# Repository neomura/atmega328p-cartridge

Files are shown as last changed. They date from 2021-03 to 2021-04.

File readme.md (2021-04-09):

# neomura/atmega328p-cartridge

Circuit design and games engine for ATMega328P-based cartridges for the Neomura retro games console.

Derived from the [Arduinocade project](https://github.com/rossumur/Arduinocade).

| Link | Description |
| --- | --- |
| [License](./license.md) | MIT License. |
| [Documentation](./documentation/readme.md) | Documentation regarding this project. |
| [Circuit Design](./circuit-design/readme.md) | KiCad files and assembly instructions for the PCB. |
| [Engine](./engine/readme.md) | Source code for the games engine. |
| [Palette](./palette.aseprite) | Aseprite palette; each group of four colors is an available palette for a scanline. |

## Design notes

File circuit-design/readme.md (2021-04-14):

# [neomura/atmega328p-cartridge](../readme.md)/Circuit Design

| Link | Description |
| --- | --- |
| [cartridge.pro](./cartridge.pro) | KiCAD project. |
| [cartridge.sch](./cartridge.sch) | KiCAD schematic. |
| [cartridge.kicad_pcb](./cartridge.kicad_pcb) | KiCAD PCB layout. |

## Bill of materials

Links are included for reference only and are not endorsements.

| Reference | Description | Model No. | Link |
| --- | --- | --- | --- |
| J1 | Cartridge connector (right-angled 1x15 2.54mm male pin header) | Unknown | [https://www.aliexpress.com/item/4000660389713.html?spm=a2g0s.9042311.0.0.65b74c4dMpBmdG](https://www.aliexpress.com/item/4000660389713.html?spm=a2g0s.9042311.0.0.65b74c4dMpBmdG) |
| J2 | ICSP header (right-angled 1.5 2.54mm male pin header) | Unknown | [https://www.bitsbox.co.uk/index.php?main_page=product_info&cPath=225_230&products_id=3128](https://www.bitsbox.co.uk/index.php?main_page=product_info&cPath=225_230&products_id=3128) |
| U1 | Microcontroller | ATMega328P-PU | [https://www.bitsbox.co.uk/index.php?main_page=product_info&cPath=140_161_162&products_id=1225](https://www.bitsbox.co.uk/index.php?main_page=product_info&cPath=140_161_162&products_id=1225) |
| X1 | 14.31818MHz (NTSC) or 17.734MHz (PAL 60) HC-49S crystal | Unknown | [https://www.aliexpress.com/item/32496964768.html?spm=a2g0s.9042311.0.0.65b74c4dMpBmdG](https://www.aliexpress.com/item/32496964768.html?spm=a2g0s.9042311.0.0.65b74c4dMpBmdG) or [https://www.ebay.co.uk/itm/20pcs-17-734MHz-HC-49S-Crystal-Oscillator-Passive-Quartz-Resonator/253056403948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](https://www.ebay.co.uk/itm/20pcs-17-734MHz-HC-49S-Crystal-Oscillator-Passive-Quartz-Resonator/253056403948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) |
| R1 | 1M load resistor | Unknown | [https://www.bitsbox.co.uk/index.php?main_page=product_info&cPath=83_84_85&products_id=480](https://www.bitsbox.co.uk/index.php?main_page=product_info&cPath=83_84_85&products_id=480) |
| C1/C2 | 22pF load capacitor | Unknown | [https://www.bitsbox.co.uk/index.php?main_page=product_info&cPath=65_75_67&products_id=187](https://www.bitsbox.co.uk/index.php?main_page=product_info&cPath=65_75_67&products_id=187) |
| D1 | Reset protection diode | 1N4148 | [https://www.bitsbox.co.uk/index.php?main_page=product_info&cPath=140_141_143&products_id=925](https://www.bitsbox.co.uk/index.php?main_page=product_info&cPath=140_141_143&products_id=925) |
| R2 | 4.7k reset pull-up resistor | Unknown | [https://www.bitsbox.co.uk/index.php?main_page=product_info&cPath=83_84_85&products_id=452](https://www.bitsbox.co.uk/index.php?main_page=product_info&cPath=83_84_85&products_id=452) |
| C3 | 100nF reset bypass capacitor | Unknown | [https://www.bitsbox.co.uk/index.php?main_page=product_info&cPath=65_75_67&products_id=210](https://www.bitsbox.co.uk/index.php?main_page=product_info&cPath=65_75_67&products_id=210) |
| C4 | 100nF +5V bypass capacitor | Unknown | [https://www.bitsbox.co.uk/index.php?main_page=product_info&cPath=65_75_67&products_id=210](https://www.bitsbox.co.uk/index.php?main_page=product_info&cPath=65_75_67&products_id=210) |
| R3 | 470R video carrier resistor | Unknown | [https://www.bitsbox.co.uk/index.php?main_page=product_info&cPath=83_84_85&products_id=441](https://www.bitsbox.co.uk/index.php?main_page=product_info&cPath=83_84_85&products_id=441) |
| R4 | 1K video sync resistor | Unknown | [https://www.bitsbox.co.uk/index.php?main_page=product_info&cPath=83_84_85&products_id=445](https://www.bitsbox.co.uk/index.php?main_page=product_info&cPath=83_84_85&products_id=445) |
| R5/R7 | 270R audio low-pass resistor | Unknown | [https://www.bitsbox.co.uk/index.php?main_page=product_info&cPath=83_84_85&products_id=438](https://www.bitsbox.co.uk/index.php?main_page=product_info&cPath=83_84_85&products_id=438) |
| C5/C7 | 33nF audio low-pass capacitor | Unknown | [https://www.bitsbox.co.uk/index.php?main_page=product_info&cPath=65_75_67&products_id=208](https://www.bitsbox.co.uk/index.php?main_page=product_info&cPath=65_75_67&products_id=208) |
| R6/R8 | 150R audio output resistor | Unknown | [https://www.bitsbox.co.uk/index.php?main_page=product_info&cPath=83_84_85&products_id=435](https://www.bitsbox.co.uk/index.php?main_page=product_info&cPath=83_84_85&products_id=435) |
| C6/C8 | 10uF audio output capacitor | Unknown | [https://www.amazon.co.uk/gp/product/B08D647KCD/ref=ppx_yo_dt_b_asin_title_o00_s00?ie=UTF8&psc=1](https://www.amazon.co.uk/gp/product/B08D647KCD/ref=ppx_yo_dt_b_asin_title_o00_s00?ie=UTF8&psc=1) |

### Possible substitutions

#### J1

Right-angled male pin headers appear to come in two distinct styles; one where the plastic retainer is in contact with the PCB, and one where it is instead in contact with the corresponding female socket.  This PCB is designed for the latter, and the former will not fit inside a cartridge shell.

#### J2

In contrast to J1, this must be the style with the plastic retainer in contact with the PCB to fit inside a cartridge shell.  This can be substituted for a vertical pin header (or a socket) if it does not need to fit inside a cartridge shell.

#### U1

Other pin-compatible ATMega ICs may work.  Note that most will have smaller flash space and may not be able to store complex games.

#### X1/R1/C1/C2

Most 14.31818MHz crystals which are HC49 or smaller will work as long as appropriate bypass capacitors and resistor are included.  To be compatible with Arduinocade games instead of Neomura games, a 28.6363MHz crystal such as [https://www.aliexpress.com/item/32910067235.html?spm=a2g0s.9042311.0.0.5bfd4c4d3a2EOO](https://www.aliexpress.com/item/32910067235.html?spm=a2g0s.9042311.0.0.5bfd4c4d3a2EOO) may be used instead.

It may be possible to omit the load resistor.

#### D1

This diode is included to prevent accidental high-voltage programming.  It can be omitted.

## Assembly instructions

- Start by soldering J1 and J2.  I would recommend using some kind of clamp such as a crocodile clip to keep it firmly attached to the board (note that it will act as a heatsink, making soldering more difficult, if in contact with pins).  Use short bursts of high heat and allow time to cool between joints to avoid melting the plastic retainer.  After soldering, use a female socket to ensure that pins are straight, and use said female socket to correct the pins if not parallel with the PCB.
- Solder all other components.  There is not much room inside the shell once constructed, so ensure that these are as close to the board top as possible and that leads are clipped short.
- Place the PCB, logo up, into the back half of the shell.
- Place the front half of the shell on top and press fit.  Be careful to ensure that no components will be crushed, such as C1 and C2; you may need to stand these at 45 degrees to avoid contact with the front half of the case.

### Program

J2 is all pins except VCC of a standard 2x3 ICSP header.  These have been arranged to match pins 10-13 of an Arduino used as a programmer.

If using an [Arduino as an ISP](https://www.arduino.cc/en/Tutorial/BuiltInExamples/ArduinoISP), connect the following pins (where the Arduino has multiple pins labelled the same, any will work):

| Arduino | ICSP  |
| --- | ----- |
| GND | GND.  |
| 5V | VCC.  |
| 13 | SCK.  |
| 12 | MISO. |
| 11 | MOSI. |
| 10 | RST.  |

#### Set fuse bits

By default, an ATMega328P will use its internal 8MHz clock rather than an external crystal.  To configure this, use [AVRDUDE](https://www.nongnu.org/avrdude/) to set the correct fuse bits:

```shell
avrdude -pM328P -Ulfuse:w:0xf7:m -Uhfuse:w:0xde:m -Uefuse:w:0xfd:m
```

Note that you will need to add command line arguments to this to specify which programmer you are using, for example:

| Programmer | Suffix |
| --- | --- |
| USBtiny | -cusbtiny |
| Arduino as ISP on COM port 3 under Windows | -cavrisp -b 19200 -Pcom3 |
| Arduino as ISP on COM port 3 under Linux | -cavrisp -b 19200 -P/dev/ttyS3 |

If you are running AVRDUDE under Windows Subsystem for Linux, you may find that the remapped COM ports do not work.  In these instances, running AVRDUDE under Windows at least once seems to resolve this.

You may see an error that the extended fuse could not be written.  This is normal, as not all of its bits are writable; it could be argued to be more of an AVRDUDE bug that it tried to check them.

#### Flash

Next, write a program to flash.  Make sure that a .hex file to write exists in the current working directory, then execute:

```shell
avrdude -pM328P -Uflash:w:name-of-your-hex-file.hex
```

As before, you will need to add command line arguments to specify the correct programmer.

After following these steps, you should be able to connect the video pin (cartridge left 1) to the composite video input on a NTSC-compatible display and see a picture.

## References

| Link | Description |
| --- | --- |
| [https://www.instructables.com/Adding-ICSP-header-to-your-ArduinoAVR-board/](https://www.instructables.com/Adding-ICSP-header-to-your-ArduinoAVR-board/) | Source for ICSP header layout. |
| [https://www.arduino.cc/en/Tutorial/BuiltInExamples/ArduinoISP](https://www.arduino.cc/en/Tutorial/BuiltInExamples/ArduinoISP) | Details on using an Arduino as an ISP. |
| [https://forum.arduino.cc/index.php?topic=71580.0](https://forum.arduino.cc/index.php?topic=71580.0) | Source for default Arduino fuses. |
| [https://www.avrfreaks.net/forum/unable-reset-fuses-atmega328p](https://www.avrfreaks.net/forum/unable-reset-fuses-atmega328p) | Workaround for AVRDUDE problem. |
| [https://www.ladyada.net/learn/avr/avrdude.html](https://www.ladyada.net/learn/avr/avrdude.html) | AVRDUDE instructions. |

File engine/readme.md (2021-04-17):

# [neomura/atmega328p-cartridge](../readme.md)/Engine

This engine is written in [AVRA assembler](https://github.com/Ro5bert/avra).

## Flow

The reset vector starts by running through setup routines for the engine and game.

It then enters the main loop, with the the engine's interrupt interacting with hardware and advancing global state which the main loop tracks to raise events.

## Registers

The ATMega328P has enough general-purpose registers that with the limited cycles available frequently used information is best kept in a register rather than repeatedly storing to (costing 2 cycles) and loading from (costing 2 cycles) SRAM.  Additionally, if registers used by the main loop and interrupts overlap as little as possible, the push (2 cycles) and pop (2 cycles) normally required to prevent corruption of main loop state from interrupts can be avoided as well.  In practice, few game logic or driver operations require more than 4 general purpose registers.

Some registers have special purposes:

- `r0` and `r1` receive the result of the instructions `fmul`, `fmuls`, `fmulsu`, `mul`, `muls` and `mulsu`.
- `r26`/`r27`, `r28`/`r29` and `r30`/`r31` are labelled `X`, `Y` and `Z` respectively and are used for indirect load, store and jump.

If these are used, they are considered to belong to the main loop, and any interrupts must back them up (using `push`) beforehand and restore them (using `pop`) before `reti` (alongside `SREG`).

`r0` through `r15` are not directly usable with the instructions `cpi`, `fmul`, `fmuls`, `fmulsu`, `muls`, `mulsu`, `cbr`, `ldi`, `lds`, `ori`, `sbci`, `sbr`, `ser`, `sts`, `subi`, `andi` or `cbr`.  Consequently, if a use is found which is not made impossible or awkward through this limitation, these registers should be prioritized to leave the more flexible r16-r31 available for other operations.

The resulting mapping is as follows:

| Register | Name | Description |
| --- | --- | --- |
| `r0` | N/A | Output for some instructions. |
| `r1` | N/A | Output for some instructions. |
| `r2` | `pad_0` | State of pad 0 (set bits indicate held buttons, ordered face right, face left, select, start, up, down, left, right; all cleared when pad disconnected). |
| `r3` | `pad_1` | State of pad 1 (set bits indicate held buttons, ordered face right, face left, select, start, up, down, left, right; all cleared when pad disconnected). |
| `r4` | `pad_2` | State of pad 2 (set bits indicate held buttons, ordered face right, face left, select, start, up, down, left, right; all cleared when pad disconnected). |
| `r5` | `pad_3` | State of pad 3 (set bits indicate held buttons, ordered face right, face left, select, start, up, down, left, right; all cleared when pad disconnected). |
| `r6` | `main_loop_previous_video_row` | Used by the main loop for state tracking. |
| `r7` | `zero` | Always contains zero. |
| `r8` | `game_general_purpose_low_a` | Available for general purpose usage, though note that many instructions cannot be used with it directly. |
| `r9` | `game_general_purpose_low_b` | Available for general purpose usage, though note that many instructions cannot be used with it directly. |
| `r10` | `game_general_purpose_low_c` | Available for general purpose usage, though note that many instructions cannot be used with it directly. |
| `r11` | `game_general_purpose_low_d` | Available for general purpose usage, though note that many instructions cannot be used with it directly. |
| `r12` | `game_general_purpose_low_e` | Available for general purpose usage, though note that many instructions cannot be used with it directly. |
| `r13` | `game_general_purpose_low_f` | Available for general purpose usage, though note that many instructions cannot be used with it directly. |
| `r14` | `game_general_purpose_low_g` | Available for general purpose usage, though note that many instructions cannot be used with it directly. |
| `r15` | `game_general_purpose_low_h` | Available for general purpose usage, though note that many instructions cannot be used with it directly. |
| `r16` | `video_next_row` | The row which the interrupt will be outputting next.  Will remain 0 for longer than other values, in which `game_tick` is executed by the main loop. |
| `r17` | `interrupt_state` | Used by the interrupt to track progress through the current frame. |
| `r18` | `interrupt_flags` | Flags used internally by by the interrupt. |
| `r19` | `game_general_purpose_high_a`  | Available for general purpose usage. |
| `r20` | `game_general_purpose_high_b`  | Available for general purpose usage. |
| `r21` | `game_general_purpose_high_c`  | Available for general purpose usage. |
| `r22` | `game_general_purpose_high_d`  | Available for general purpose usage. |
| `r23` | `game_general_purpose_high_e`  | Available for general purpose usage. |
| `r24` | `game_general_purpose_high_f`  | Available for general purpose usage. |
| `r25` | `game_general_purpose_high_g`  | Available for general purpose usage. |
| `r26` | N/A | `X` (low). |
| `r27` | N/A | `X` (high). |
| `r28` | N/A | `Y` (low). |
| `r29` | N/A | `Y` (high). |
| `r30` | N/A | `Z` (low). |
| `r31` | N/A | `Z` (high). |

## Creating a game

Use AVRA to compile the engine's [main file](./engine/main.asm).

This directory and your game's source directory must be added as include paths.

Define exactly one of the following to select a video standard:

- `NTSC`
- `PAL_60`

An example command line is as follows, assuming that the current working directory is the game's source directory:

`avra -o game.hex submodules/neomura/atmega328p-cartridge/engine/engine/main.asm --includedir submodules/neomura/atmega328p-cartridge/engine --define NTSC`

This expects a number of files to exist:

### [`game/declarations/index.asm`](../example/game/declarations/index.asm)

Use this file to declare any constants, SRAM or register mappings which will be used in other files.  You will need to include the globals of any [drivers](./engine/drivers/readme.md) you use.

### [`game/implementation/setup.asm`](../example/game/implementation/setup.asm)

Use this file to configure any SRAM or registers prior to the game starting.  `r31` should be safe to use here.

### [`game/implementation/frame.asm`](../example/game/implementation/frame.asm)

This file is executed once per frame, by the main loop.  It is executed before the first execution of `game/row.asm` during a frame.  This is the only time that pad state registers should be read from.

### [`game/implementation/row.asm`](../example/game/implementation/row.asm)

This file is executed once per pixel row, by the main loop.  It should be used to communicate prepare the next line's framebuffer.

### [`game/implementation/sample.asm`](../example/game/implementation/sample.asm)

This file is executed by the interrupt once per audio sample, at approximately 15750Hz.  `r28`, `r29`, `r30` and `r31` can be freely clobbered; any other registers must be `push`ed before use and `pop`ped before exit if they are used anywhere else in the program.

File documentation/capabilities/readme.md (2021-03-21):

# [neomura/atmega328p-cartridge](../../readme.md)/[Documentation](../readme.md)/Capabilities

## Video

| Specification  | Value |
| --- | --- |
| Video standard | NTSC or PAL 60. |
| Resolution | 156x113. |
| Refresh rate | 60Hz. |
| Colors | 6, selecting 1 of 2 palettes of 4 colors per line. |

### Palette

Palette.

Colors as captured from a prototype unit running into a CSL USB 2.0 Audio/Video Grabber and will likely differ.

## Audio

| Specification | Value |
| --- | --- |
| Channels | 2 |
| Bit depth | 8 |
| Sample Rate | 15,699.72587719298Hz |

## Pads

Up to 4 pads are simultaneously supported.

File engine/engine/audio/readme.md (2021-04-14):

# [neomura/atmega328p-cartridge](../../../readme.md)/[Engine](../../readme.md)/Audio
TODO
These helper functions generate various waveforms which can be mixed to produce game audio.

| Link | Description |
| --- | --- |
| [Noise (mono)](./noise_mono/readme.md) | Monaural 15-bit linear-feedback shift register noise generator. |
| [Pulse (mono)](./pulse_mono/readme.md) | Monaural pulse wave generator with variable duty cycle. |
| [Sawtooth (mono)](./sawtooth_mono/readme.md) | Monaural rising sawtooth wave generator. |
| [Triangle (mono)](./triangle_mono/readme.md) | Monaural triangle wave generator. |

## Pattern

Most will follow a pattern like the following, assuming that the oscillator is called "example":

```assembly
; This is a block of bytes which will control the oscillator and allow it to track its state between samples.
example_register: .byte AUDIO_EXAMPLE_REGISTER_BYTES

.macro game_setup
  audio_example_setup example_register, r16
.endm

.macro game_frame
  ; Oscillators will include helpers to read/write specific areas of their registers.
  ; Frequency control uses a "rate", which is the amount by which their internal counters increment every sample.
  lds r16, example_register + AUDIO_EXAMPLE_REGISTER_RATE

  ; Increase this rate once per frame.
  inc r16

  lds example_register + AUDIO_EXAMPLE_REGISTER_RATE, r16
.endm

.macro game_sample
  ; Most oscillators use r0 and r1.
  push r0
  push r1

  ; Generate the next audio sample.  Most oscillators output to r1.
  audio_example_sample example_register

  out OCR0B, r1
  out OCR0A, r1

  pop r1
  pop r0
.endm
```

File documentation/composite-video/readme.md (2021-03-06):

# [neomura/atmega328p-cartridge](../../readme.md)/[Documentation](../readme.md)/Composite Video

Composite video is that which flows over the yellow cable of the yellow-white-and-red RCA cables often seen on games consoles between 1990 and 2010.

While it is a video protocol, the way in which it works is tightly bound to how a classic CRT (boxy) TV works, which must also be understood to appreciate why composite video is specified how it is.

CRT TV.

A CRT TV has a glass screen which displays a picture.  Behind it is an electron gun.  When energized, this fires a laser-like beam of electrons at the back of the glass, which illuminates a spot of the phosphor on the rear side of the glass.  The electron gun's output can be be controlled electronically to change the brightness of this spot.  Electromagentic coils can then deflect this beam of electrons between the gun and the glass, which allows the spot to be moved around the screen electronically.

Early arcade games directly interfaced the game with these electromagnetic coils, such as Atari's Battlezone, Star Wars and Tempest, allowing for crisp line drawings to be shown.  Composite video does not grant this level of control; instead, the beam scans from the top of the screen to the bottom, zig-zagging from left to right and back on the way down.

Zig-zag pattern.

To start a frame (pull the gun to the top of the screen), a VSYNC (vertical synchronization) signal is sent.  This is a pulse wave alternating between 0 and -40 IRE (1 IRE = 1/140V).

Example odd vertical sync signal.

| Statistic | | | | | | | | | | | | | | | | | | | | | | | | | | | | | | | | |
| --- | --- | -- | --- | -- | --- | -- | --- | -- | --- | -- | --- | -- | --- | - | --- | - | --- | - | --- | - | --- | - | --- | -- | --- | -- | --- | -- | --- | -- | --- | -- |
| Duration (µs) | 2 | 30 | 2 | 30 | 2 | 30 | 2 | 30 | 2 | 30 | 2 | 30 | 30  | 2 | 30  | 2 | 30  | 2 | 30  | 2 | 30  | 2 | 2 | 30 | 2 | 30 | 2 | 30 | 2 | 30 | 2 | 30 |
| Level (IRE) | -40 | 0  | -40 | 0  | -40 | 0  | -40 | 0  | -40 | 0  | -40 | 0  | -40 | 0 | -40 | 0 | -40 | 0 | -40 | 0 | -40 | 0 | -40 | 0  | -40 | 0  | -40 | 0  | -40 | 0  | -40 | 0  |

The middle section which spends more time at -40IRE than 0IRE is the VSYNC signal itself; the preceding and following signals are known as equalization pulses and exist to assist the electronics in older TVs.

After this signal, a repeating pattern is sent:

Example signal for a scanline.

First is a 4.7µs -40IRE HSYNC (horizontal synchronization) pulse.  This instructs the TV to return the gun to the left of the screen.  There is a short "porch" in which 0IRE is sent, and then, the active video region.

The active region is an analog segment in which voltages between 7.5IRE and 100IRE map to the full luminance range available; 7.5IRE represents black, and 100IRE represents white.  Given the above signal, you could expect to see:

Above example, rasterized.

After the active region, there is another, shorter porch of 0IRE.

These timings break down as:

| Duration (µs) | Description |
| --- | --- |
| 4.7 | HSYNC pulse.  |
| 4.7 | Porch. |
| 52.6 | Active video. |
| 1.5 | Porch. |

Totalling 63.5µs.

This will repeat until the next VSYNC signal.  This VSYNC signal, however, will be somewhat different:

Example even vertical sync signal.

| Statistic | | | | | | | | | | | | | | | | | | | | | | | | | | | | |
| --- | --- | -- | --- | -- | --- | -- | --- | -- | --- | -- | --- | - | --- | - | --- | - | --- | - | --- | - | --- | -- | --- | -- | --- | -- | --- | -- |
| Duration (µs) | 2 | 30 | 2 | 30 | 2 | 30 | 2 | 30 | 2 | 30 | 30  | 2 | 30  | 2 | 30  | 2 | 30  | 2 | 30  | 2 | 2 | 30 | 2 | 30 | 2 | 30 | 2 | 30 |
| Level (IRE) | -40 | 0  | -40 | 0  | -40 | 0  | -40 | 0  | -40 | 0  | -40 | 0 | -40 | 0 | -40 | 0 | -40 | 0 | -40 | 0 | -40 | 0  | -40 | 0  | -40 | 0  | -40 | 0  |

The reason for this is that composite video is interlaced; as early TV signals had limited bandwidth, only 30FPS worth of pixel data was possible.  However, if the screen was scanned at only 30Hz, a noticeable flicker would be present.  To work around this, each screen is actually scanned twice per frame (60Hz; usually matching the local mains frequency to prevent rolling brightness pulses due to the interference pattern between poorly regulated power supply and refresh rate), each time only illuminating alternating rows (so that when both fields of the frame are overlaid, a complete picture is drawn).  The two types of VSYNC signal distinguish between the "odd" and "even" fields.

A total of 525 lines is composed as follows:

| Lines | Description |
| --- | --- |
| 8 | Vertical sync (odd). |
| 15 | Blank lines (just horizontal sync). |
| 240 | Active lines (odd). |
| 6.5 | Vertical sync (even). |
| 15.5 | Blank lines (just horizontal sync). |
| 240 | Active lines (even). |

As specified, composite video has (frame) resolution of 640x480.  However, timings varied greatly on early transmitters and TVs, so content near the edges of this visible area were sometimes cropped.  Broadcasters have (unfortunately bespoke) internal standards defining what they consider to be the "title safe area" (text, etc. usually 80% of the display) and the "action safe area" (usually 90% of the display).

## References

| Link | Description |
| --- | --- |
| [https://www.maximintegrated.com/en/design/technical-documents/tutorials/7/734.html#Composite/CVBS%20Interface](https://www.maximintegrated.com/en/design/technical-documents/tutorials/7/734.html#Composite/CVBS%20Interface) | Details on how NTSC composite video works. |
| [https://videocide.com/glossary/vertical-sync/](https://videocide.com/glossary/vertical-sync/) | Details on vertical sync timing. |

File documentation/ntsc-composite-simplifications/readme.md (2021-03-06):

# [neomura/atmega328p-cartridge](../../readme.md)/[Documentation](../readme.md)/NTSC Composite Simplifications

Generating a correct NTSC composite video signal from a microcontroller is quite difficult without custom silicon such as the AD725 as found in the Uzebox.  Most retro consoles included complex region-specific analog electronics to convert signals from their graphics processors into NTSC composite video signals.  To keep cost down, these usually took a number of shortcuts to produce a signal which would still work, but is not entirely correct.

Lines can be lengthened very slightly so that they are an even multiple in duration of the colorburst interval (63.5µs -> 63.7µs).

The equalizing pulses around VSYNC can usually be omitted entirely; they are only needed by older TVs from before the 1980s.

The timing of the VSYNC signal itself can be shortened to match normal lines (64µs -> 63.7µs), simplifying timing, while the second pulse within that "line" can also be dropped.

Most retro consoles only emit one field repeatedly (either even or odd).  This halves their vertical resolution to 240 rows, but removes the need to consider interlacing, and increases framerate to 60Hz.

Similar to how grayscale TVs ignore the sine wave added for color as it is outside their expected frequency space, color TVs ignore content significantly above their expected 3.579545MHz carrier frequency.  As a consequence, pulse waves can stand in for sine waves as TVs will filter off the upper harmonics.

This is part of what constitutes an "artifact color", a singificant contributor to the Apple II's unique look.

## References

| Link | Description |
| --- | --- |
| [https://www.hdretrovision.com/blog/2018/10/22/engineering-csync-part-1-setting-the-stage](https://www.hdretrovision.com/blog/2018/10/22/engineering-csync-part-1-setting-the-stage) | Details on 240p60 mode, and simplified VSYNC. |
| [https://www.eevblog.com/forum/beginners/ntsc-composite-timing-for-retroconsoles/msg3483262/#msg3483262](https://www.eevblog.com/forum/beginners/ntsc-composite-timing-for-retroconsoles/msg3483262/#msg3483262) | Details on how line length and colorburst interval interact. |
| [http://nerdlypleasures.blogspot.com/2013/09/the-overlooked-artifact-color.html](http://nerdlypleasures.blogspot.com/2013/09/the-overlooked-artifact-color.html) | Details on artifact color. |

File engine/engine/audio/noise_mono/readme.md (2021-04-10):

# [neomura/atmega328p-cartridge](../../../../readme.md)/[Engine](../../../readme.md)/[Audio](../readme.md)/Noise (mono)

Monaural 15-bit linear-feedback shift register noise generator.

## Registers

| Name | Type | Description |
| --- | ---- | --- |
| `AUDIO_NOISE_MONO_REGISTER_RATE` | `U8` | The oscillator advances to the next bit every 256 / `AUDIO_NOISE_MONO_REGISTER_RATE` samples. |
| `AUDIO_NOISE_MONO_REGISTER_AMPLITUDE` | `U8` | Output alternates between 0 and `AUDIO_NOISE_MONO_REGISTER_AMPLITUDE`. |

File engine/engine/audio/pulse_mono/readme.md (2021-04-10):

# [neomura/atmega328p-cartridge](../../../../readme.md)/[Engine](../../../readme.md)/[Audio](../readme.md)/Pulse (mono)

Monaural pulse wave generator with variable duty cycle.

## Registers

| Name | Type  | Description |
| --- | ----- | --- |
| `AUDIO_PULSE_MONO_REGISTER_RATE` | `U16` | The oscillator completes one cycle every 65536 / `AUDIO_PULSE_MONO_REGISTER_RATE` samples. |
| `AUDIO_PULSE_MONO_REGISTER_AMPLITUDE` | `U8`  | Output alternates between 0 and `AUDIO_PULSE_MONO_REGISTER_AMPLITUDE`. |
| `AUDIO_PULSE_MONO_REGISTER_DUTY` | `U8`  | The point during a cycle at which the oscillator switches from `AUDIO_PULSE_MONO_REGISTER_AMPLITUDE` to 0.  0 = at the start, 128 = 50% duty (square), 255 = at the end. |

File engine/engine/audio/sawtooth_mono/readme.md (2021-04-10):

# [neomura/atmega328p-cartridge](../../../../readme.md)/[Engine](../../../readme.md)/[Audio](../readme.md)/Sawtooth (mono)

Monaural rising sawtooth wave generator.

## Registers

| Name | Type  | Description |
| --- | ----- | --- |
| `AUDIO_SAWTOOTH_MONO_REGISTER_RATE` | `U16` | The oscillator completes one cycle every 65536 / `AUDIO_SAWTOOTH_MONO_REGISTER_RATE` samples. |
| `AUDIO_SAWTOOTH_MONO_REGISTER_AMPLITUDE` | `U8`  | Output travels from 0 to `AUDIO_SAWTOOTH_MONO_REGISTER_AMPLITUDE`. |

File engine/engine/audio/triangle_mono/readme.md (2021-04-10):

# [neomura/atmega328p-cartridge](../../../../readme.md)/[Engine](../../../readme.md)/[Audio](../readme.md)/Triangle (mono)

Monaural triangle wave generator.

## Registers

| Name | Type | Description |
| --- | --- | --- |
| `AUDIO_TRIANGLE_MONO_REGISTER_RATE` | `U16` | The oscillator completes one cycle every 65536 / `AUDIO_TRIANGLE_MONO_REGISTER_RATE` samples. |
| `AUDIO_TRIANGLE_MONO_REGISTER_AMPLITUDE` | `U8` | Output travels from 0 to `AUDIO_TRIANGLE_MONO_REGISTER_AMPLITUDE` / 2 and back to 0. |

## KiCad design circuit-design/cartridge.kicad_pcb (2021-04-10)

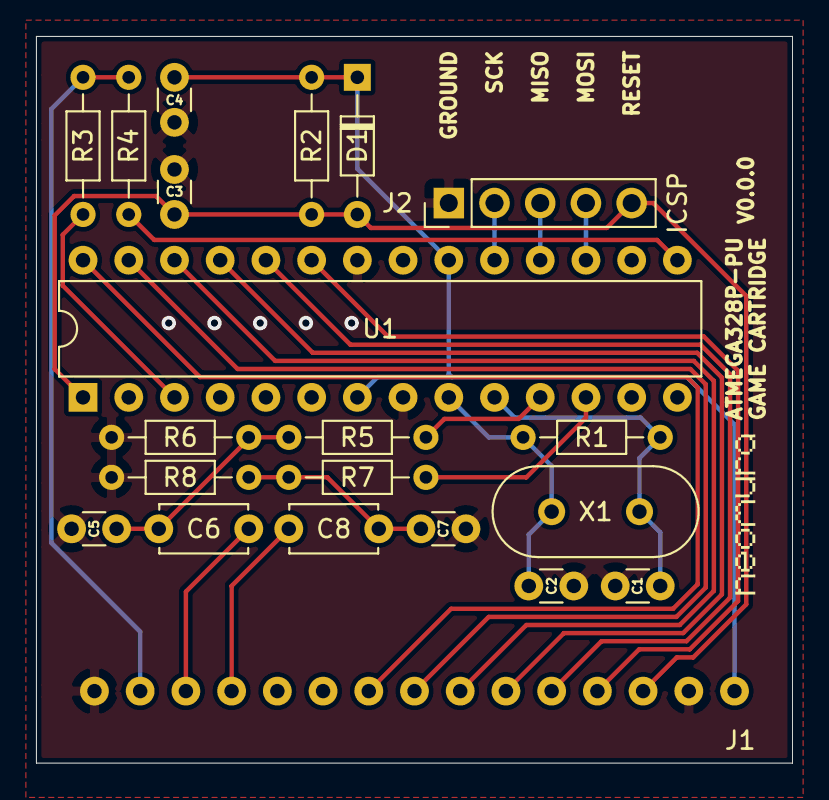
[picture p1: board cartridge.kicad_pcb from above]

Board: 2 copper layers, 42.0 x 40.4 mm, 22 parts (0 on the bottom side), 23 nets.

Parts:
C1, C2: 22pF; C_Disc_D3.0mm_W1.6mm_P2.50mm
C3, C4: 100nF; C_Disc_D3.0mm_W1.6mm_P2.50mm
C5, C7: 33n; C_Disc_D3.0mm_W1.6mm_P2.50mm
C6, C8: 10uF; C_Disc_D4.7mm_W2.5mm_P5.00mm
D1: 1N4148; D_DO-34_SOD68_P7.62mm_Horizontal
J1: Connector; Cartridge
J2: ICSP; PinHeader_1x05_P2.54mm_Vertical
R1: 1M; R_Axial_DIN0204_L3.6mm_D1.6mm_P7.62mm_Horizontal
R2: 4.7K; R_Axial_DIN0204_L3.6mm_D1.6mm_P7.62mm_Horizontal
R3: 470R; R_Axial_DIN0204_L3.6mm_D1.6mm_P7.62mm_Horizontal
R4: 1K; R_Axial_DIN0204_L3.6mm_D1.6mm_P7.62mm_Horizontal
R5, R7: 270R; R_Axial_DIN0204_L3.6mm_D1.6mm_P7.62mm_Horizontal
R6, R8: 150R; R_Axial_DIN0204_L3.6mm_D1.6mm_P7.62mm_Horizontal
Ref**: Val**; Front-Silkscreen
U1: ATmega328P-PU; DIP-28_W7.62mm
X1: 14.31818MHz (NTSC) or 17.734MHz (PAL 60); Crystal_HC49-4H_Vertical

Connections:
+5V: C4.1, D1.1, J1.15, R2.1, U1.7, U1.20
AUDIO_L: C6.1, J1.3
AUDIO_PWM_L: R5.2, U1.11
AUDIO_PWM_R: R7.2, U1.12
AUDIO_R: C8.1, J1.4
GND: C1.1, C2.2, C3.2, C4.2, C5.1, C7.1, J1.1, J1.14, J2.1, R6.2, R8.2, U1.8, U1.22
MISO: J2.3, U1.18
MOSI: J2.4, U1.17
unnamed: C5.2, C6.2, R5.1, R6.1
unnamed: C7.2, C8.2, R7.1, R8.1
PAD_0_DATA: J1.9, U1.26
PAD_1_DATA: J1.10, U1.25
PAD_2_DATA: J1.11, U1.24
PAD_3_DATA: J1.12, U1.23
PAD_CLOCK: J1.8, U1.27
PAD_LATCH: J1.7, U1.28
RESET: C3.1, D1.2, J1.13, J2.5, R2.2, U1.1
SCK: J2.2, U1.19
VIDEO: J1.2, R3.2, R4.1
VIDEO_CARRIER: R3.1, U1.3
VIDEO_HSYNC: R4.2, U1.15
XTAL1: C2.1, R1.2, U1.9, X1.2
XTAL2: C1.2, R1.1, U1.10, X1.1

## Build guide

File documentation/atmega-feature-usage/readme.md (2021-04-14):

# [neomura/atmega328p-cartridge](../../readme.md)/[Documentation](../readme.md)/ATMega Feature Usage

This project derives from Arduinocade, so much of what this document describes is similar to Arduinocade.

## Video

The ATMega range has a number of hardware timers which can repeatedly count CPU cycles in the background while the program executes.  Most timers are 8-bit, but timer 1 is always 16-bit.  This timer is configured to count the number of CPU cycles on a NTSC line.

Each timer has 2 or more channels; each being a comparison value and either a GPIO pin which can be directly controlled by the timer, or an interrupt which can be raised to act upon it.

The first channel is used to produce the HSYNC and VSYNC pulses; it is configured to directly control a GPIO pin, with the comparison value changed to switch between the two signals.

The second channel is used to trigger an interrupt (which is where the above comparison value change is performed).  The colorburst and active video content are generated by serial output during this interrupt, which, at its maximum speed, can output 7.15909MBit/s; one bit every two CPU cycles, in batches of 8.  Phase can be adjusted by a single CPU cycle two select one of two palettes per line.

The HSYNC/VSYNC pulse GPIO and serial output are combined using a resistor divider.

| Pin | ATMega328P | Arduino | Resistor |
| --- | --- | --- | --- |
| HSYNC/VSYNC pulse GPIO | PB1 | 9 | 1K |
| Serial output | PD1 | 1 | 470R |

When the 75R input impedence of the receiving system is taken into account, this produces the following voltages, though, only approximately:

| HSYNC/VSYNC pulse GPIO | Serial output | Voltage | IRE | Offset IRE |
| --- | --- | --- | --- | --- |
| 0V | 0V | 0V | 0 | -42 |
| 5V | 0V | 0.303748V | 42.52472  | 0.52472 |
| 0V | 5V | 0.646273V | 90.47822  | 48.47822 |
| 5V | 5V | 0.950022V | 133.00308 | 91.00308 |

This produces values offset by approximately 40 IRE.  This will, however, still work.

## Audio

An 8-bit timer is used to generate stereo audio; two channels are configured to directly control GPIO pins, which are then filtered through basic RC bandpasses based upon the Raspberry Pi's audio output circuitry.

The channels' comparison values are updated during the video interrupt, allowing for pulse width modulated audio.

## Pads

All pads are directly connected to GPIO:

| Cartridge pin | ATMega328P | Arduino |
| --- | --- | --- |
| PAD_LATCH | PC5 | A5 |
| PAD_CLOCK | PC4 | A4 |
| PAD_DATA_0 | PC3 | A3 |
| PAD_DATA_1 | PC2 | A2 |
| PAD_DATA_2 | PC1 | A1 |
| PAD_DATA_3 | PC0 | A0 |

Internal pull-ups are enabled on the data input pins.

## References

| Link | Description |
| --- | --- |
| [https://github.com/rossumur/Arduinocade](https://github.com/rossumur/Arduinocade) | Arduinocade project, from which this was derived. |
| [https://hackaday.com/2018/07/13/behind-the-pin-how-the-raspberry-pi-gets-its-audio/](https://hackaday.com/2018/07/13/behind-the-pin-how-the-raspberry-pi-gets-its-audio/) | Schematics for the Raspberry Pi's audio output. |

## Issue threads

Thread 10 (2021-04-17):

PAL 60 stretching

jameswilddev, 2021-04-17:
Stretch the viewport when using PAL 60 as it's currently too narrow.

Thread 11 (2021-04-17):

Black and white 16MHz mode

jameswilddev, 2021-04-17:
It'd be neat to include a 16MHz mode so that people can play the games on an Arduino in black and white.

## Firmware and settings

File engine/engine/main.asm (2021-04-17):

.include "m328Pdef.inc"

.dseg

.include "engine/utilities/declarations/index.asm"
.include "engine/audio/declarations/index.asm"
.include "engine/video/declarations/index.asm"
.include "engine/interrupt/declarations/index.asm"
.include "engine/pads/declarations/index.asm"
.include "engine/main-loop/declarations/index.asm"
.include "game/declarations/index.asm"

.cseg

.org 0x00
  jmp main

.include "engine/interrupt/implementation/handler/index.asm"

main:
  .include "engine/utilities/implementation/setup.asm"
  .include "engine/audio/implementation/setup.asm"
  .include "engine/video/implementation/setup.asm"
  .include "engine/pads/implementation/setup.asm"
  .include "engine/main-loop/implementation/setup.asm"
  .include "game/implementation/setup.asm"
  .include "engine/interrupt/implementation/setup.asm"

  .include "engine/main-loop/implementation/run.asm"

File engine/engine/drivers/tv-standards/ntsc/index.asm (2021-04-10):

; Approximately 63.5usec, the duration of a scanline in CPU cycles, rounded to the nearest multiple of the colorburst frequency.
.equ TV_STANDARD_NTSC_SCANLINE_CYCLES = 911

; Approximately 4.7usec, the duration of a HSYNC pulse in CPU cycles.
.equ TV_STANDARD_NTSC_HSYNC_PULSE_CYCLES = 66

; Approximately 58.8usec, the duration of of a VSYNC pulse in CPU cycles.
.equ TV_STANDARD_NTSC_VSYNC_PULSE_CYCLES = 840

; Approximately 5.3usec, the point during a line at which the colorburst starts.
.equ TV_STANDARD_NTSC_COLORBURST_START_CYCLES = 76

; Approximately 12.85usec, the point during a line at which active video starts, plus a safe area border.
.equ TV_STANDARD_NTSC_ACTIVE_VIDEO_START_CYCLES = 174

; The number of VSYNC lines per frame.
.equ TV_STANDARD_NTSC_VSYNC_LINES = 3

; The number of lines between the VSYNC and active lines.
.equ TV_STANDARD_NTSC_PRE_BLANK_LINES = 27

; The number of lines between the VSYNC and active lines.
.equ TV_STANDARD_NTSC_POST_BLANK_LINES = 9

; The first VSYNC line.
.equ TV_STANDARD_NTSC_STATE_VSYNC_START = 0

; The last VSYNC line.
.equ TV_STANDARD_NTSC_STATE_VSYNC_END = TV_STANDARD_NTSC_VSYNC_LINES - 1

; The first pre-active blank line.
.equ TV_STANDARD_NTSC_STATE_PRE_BLANK_START = TV_STANDARD_NTSC_VSYNC_LINES

; The last pre-active blank line.
.equ TV_STANDARD_NTSC_STATE_PRE_BLANK_END = TV_STANDARD_NTSC_STATE_VSYNC_END + TV_STANDARD_NTSC_PRE_BLANK_LINES

; The first repeat of an active line.
.equ TV_STANDARD_NTSC_STATE_ACTIVE_A = TV_STANDARD_NTSC_STATE_PRE_BLANK_END + 1

; The second repeat of an active line.
.equ TV_STANDARD_NTSC_STATE_ACTIVE_B = TV_STANDARD_NTSC_STATE_ACTIVE_A + 1

; The first post-active blank line.
.equ TV_STANDARD_NTSC_STATE_POST_BLANK_START = TV_STANDARD_NTSC_STATE_ACTIVE_B + 1

; The last post-active blank line.
.equ TV_STANDARD_NTSC_STATE_POST_BLANK_END = TV_STANDARD_NTSC_STATE_ACTIVE_B + TV_STANDARD_NTSC_POST_BLANK_LINES

; Tracks the progress through the current frame (see TV_STANDARD_NTSC_STATE_*).
; TODO is there a better way of doing this?
.def tv_standard_ntsc_state = r23 ; tv_standard_general_purpose_high_a

.cseg

.include "engine/drivers/tv-standards/ntsc/interrupt/index.asm"

.macro tv_standard_setup
  ldi tv_standard_ntsc_state, TV_STANDARD_NTSC_STATE_POST_BLANK_START


  ; Configure timer 1.
  ; - Set "compare match" mode - OC1A will be pulled high on reaching OCR1A, then pulled low on wrapping back to 0.
  ; - Set "fast PWM" mode.
  ; - Disable the clock divider.
  store_immediate TCCR1A, r31, (1 << COM1A1) | (1 << COM1A0) | (1 << WGM11)
  store_immediate TCCR1B, r31, (1 << WGM12) | (1 << WGM13) | (1 << CS10)

  ; Use the first channel to output the first HSYNC pulse.
  store_immediate_16 ICR1L, r31, TV_STANDARD_NTSC_SCANLINE_CYCLES
  store_immediate_16 OCR1AL, r31, TV_STANDARD_NTSC_HSYNC_PULSE_CYCLES

  ; Use the second channel to trigger an interrupt which fires a little earlier than the end of a HSYNC pulse.
  ; This figure has been set as high as possible without overwhelming the timing jitter correction through experimentation.
  ; TODO check whether moveable.
  store_immediate_16 OCR1BL, r31, 44
  store_immediate TIMSK1, r31, 1<<OCIE1B


  ; Disable the SPI clock divider.
  store_immediate_16 UBRR0L, r31, 0

  ; Enable Master SPI mode.
  store_immediate UCSR0C, r31, (1<<UMSEL01)|(1<<UMSEL00)

  ; Set the TX pin as an output.  SPI will still work if this isn't done, but
  ; it will be high during inactivity rather than low.
  sbi DDRD, DDD1
.endm

.macro tv_standard_start
  ; Enable the VSYNC/HSYNC output.
  sbi DDRB, DDB1

  ; Enable the interrupt.
  sei
.endm

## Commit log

2021-02-03 Document post-assembly instructions.
2021-02-10 Add initial version of circuit design.
    [cartridge.kicad_pcb, cartridge.sch]
2021-02-11 Update footprints.
    [cartridge.kicad_pcb]
2021-02-13 Update BOM and assembly instructions.
2021-02-20 Redesign; uses the new cartridge connector, a smaller crystal, ICSP header, and improved audio.
    [cartridge.kicad_pcb, cartridge.sch]
2021-02-20 Add reference for offset voltages being fine.
2021-02-20 Fix fuse documentation.
2021-02-22 Correct resistor reading.
2021-02-23 Measure real components and update schematic/PCB layout to match. This version was sent to prototype manufacturing.
    [cartridge.kicad_pcb, cartridge.sch]
2021-02-26 Update palettes based upon observations of real circuit.
2021-03-06 Add PAL 60 crystals to BOM and schematic.
    [cartridge.sch]
2021-03-21 Begin building out drivers.
2021-03-26 Switch to full swing oscillator mode.
2021-03-27 Add warning regarding case interference.
2021-04-02 Fix wrong lines being read from (this was masked by a bug in the NTSC driver).
    [index.asm]
2021-04-08 Fix pads not being initialized.
    [main.asm]
2021-04-08 Fix long game_frame implementations causing build errors.
    [main.asm]
2021-04-10 Revise circuit design to remove (potentially dangerous) ICSP VCC pin and remove the need for an adapter to an Arduino.
    [cartridge.kicad_pcb, cartridge.sch]
2021-04-11 Move pad polling into the TV interrupt - this is both much smaller in instruction count now by the order of hundreds of bytes, and pads are polled during the active video lines, which means they won'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
    [index.asm, setup.asm]
2021-04-11 Begin merging TV standard drivers.
2021-04-14 Significant overhaul of the engine to remove the driver concept.
2021-04-14 Clarify palette switching.
2021-04-14 Fix interrupt flags not being initialized.
    [setup.asm]
